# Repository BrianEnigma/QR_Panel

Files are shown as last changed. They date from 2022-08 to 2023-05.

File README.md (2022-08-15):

# QR Panel

Action Gif

## Overview

I recently ran across [a photo meme](https://www.reddit.com/r/DidntKnowIWantedThat/comments/kwxd3a/i_have_this_qr_code_sitting_behind_me_in_zoom/) which I guess has been kicking around for a couple of years, but was new to me. It shows off a QR code that, when scanned, turns in a table lamp sitting next to it. The person posting it mentioned it's in the background of video calls. I'm on a lot of video calls, and thought this would be an interesting project to re-make.

My QR panel is a self-contained unit that only needs power and WiFi. There are multicolor LEDs inside that shine through the QR code. When scanned, it takes you to a website that picks two random colors for you, and then sends those colors over an IoT MQTT queue to the panel. The panel then does a little 5-second spinny animation with those colors. With only 8 colors to choose from, the combinations aren't infinite, but are large enough (`8 choose 2 == 56`) for you to verify that you were the one that kicked off the animation.

This work is copyright 2022 by [Brian Enigma](https://github.com/BrianEnigma). It is licensed under a <a rel="license" href="http://creativecommons.org/licenses/by-nc-sa/3.0/">Creative Commons Attribution-NonCommercial-ShareAlike 3.0 Unported License</a>.

## Prior Work

This is based on some earlier work I did with the [Adafruit Feather Huzzah](https://www.adafruit.com/product/2821) and AWS IoT message queues. [You can find that work on my blog.](https://netninja.com/2022/08/11/using-the-adafruit-feather-huzzah-with-aws-iot/)

## Target Audience

This is presented mainly as a code repo of the physical pieces (laser cut and 3D printed), Feather firmware, and cloud software that went into this device. There is not a lot of hand-holding or instruction. The target audience has access to a laser cutter and 3D printer, knows how to solder, can program an Arduino-like device, and knows their way around the AWS control panel. While the blog post linked to in the “Prior Work” section, above, does a lot of hand-holding, this one does not.

## Bill of Material

- [Feather Huzzah](https://www.adafruit.com/product/2821)
- [NeoPixel string](https://www.adafruit.com/product/1138?length=1) (mine ended up being 52 LEDs)
- [Power Supply](https://www.adafruit.com/product/1466)
- [Power Connector](https://www.adafruit.com/product/368)
- [Microswitch](https://www.adafruit.com/product/1489)
- Four M3 screws for the corners: 30mm long, with nuts and nylon washers.
- Four M2 screws for the Feather: 10mm long, with nuts and nylon washers.
- [3D Parts](3D Parts/)
    - Four 3D printed corners (white)
- 1/8" Acrylic [Laser Parts](Laser Parts/)
    - One laser-cut back panel (black)
    - Four laser-cut edges (white)
    - One laser-cut front panel (translucent). I also added some cardstock behind it to better diffuse the light. It is important to fill in the etched QR code with black acrylic paint **BEFORE** peeling off the protective masking, since it doubles as a paint mask. You might need more than one coat. Once it's try, you can peel it off.
- Solder, wire, tape, glue, etc.

## QR Customization

You'll obviously need to change the QR Code etched in the front panel or you'll end up pointing to my panel's endpoint. I used the npm [qrcode](https://www.npmjs.com/package/qrcode) package.

## Hardware Frame

The hardware frame goes together easily. Four M3 screws go through the back panel, one at each corner. Each corner has a 3D printed piece. It has registration tabs that only align to the back panel in one way. The four edges clip into the corners, snapping into retaining tabs. The LED strip gets hot-glued around the outside (around the reset microswitch), facing inward. When everything's wired up and functioning, the front panel QR code affixes to the front.

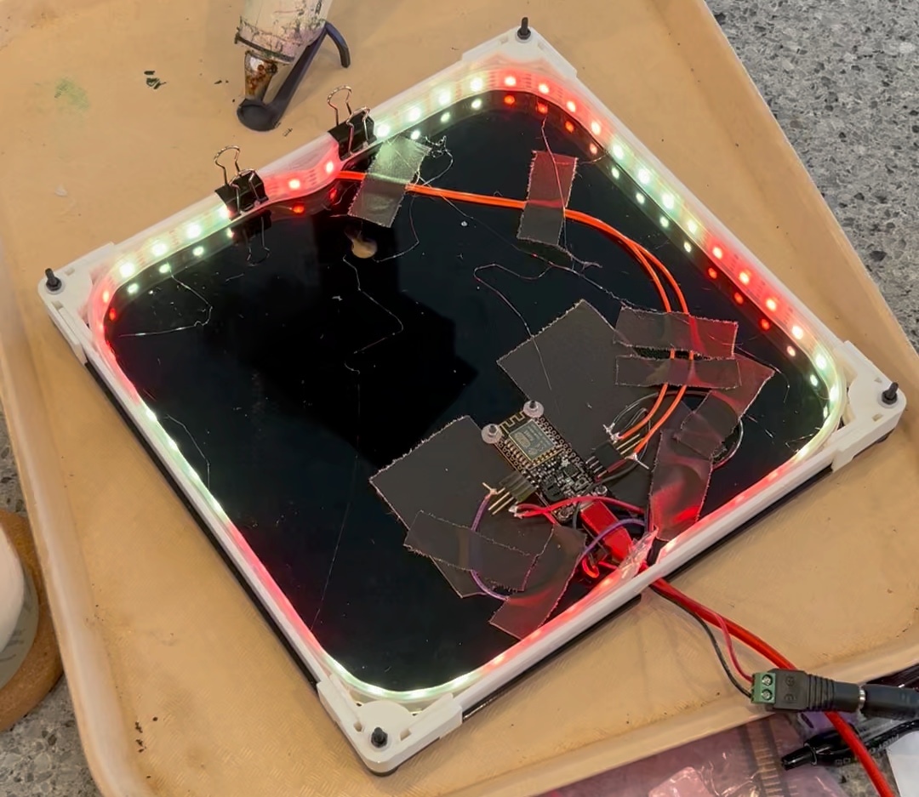
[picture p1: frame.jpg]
Frame

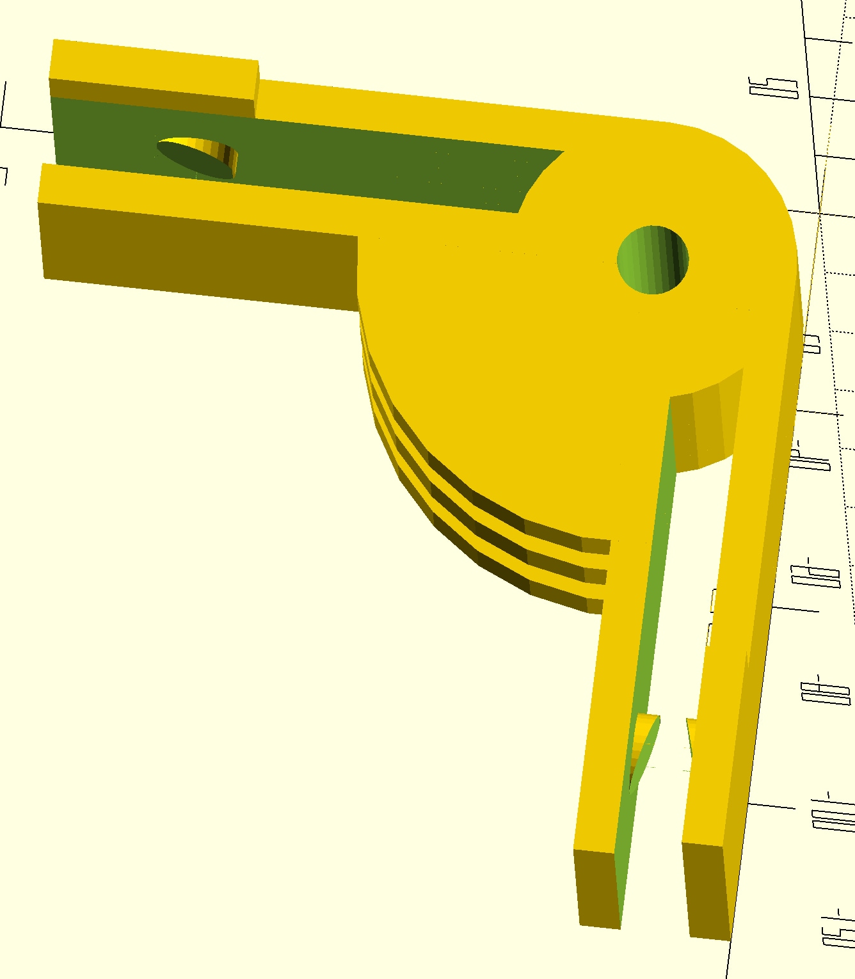
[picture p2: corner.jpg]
Corner

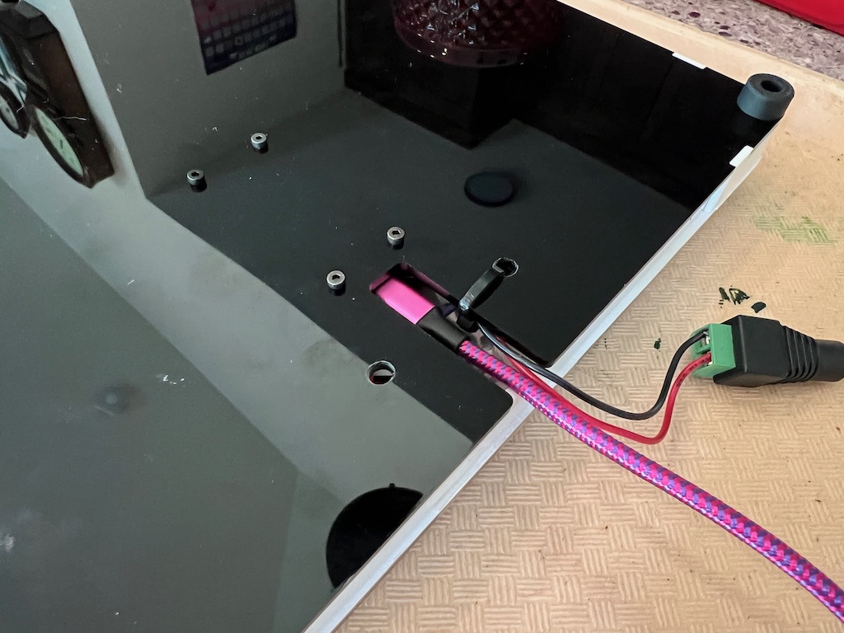
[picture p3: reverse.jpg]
Reverse


## Hardware Wiring

The hardware is fairly trivial:

- The microswitch goes to the little hole in the top. It connects between the Reset and Ground pins. It lets you “reboot” if there's a problem.
- Power gets wired from the power connector to the Battery and Ground pins.
- Power is also routed to the LED strip.
- Data is wired from pin 14 to the LED strip.

I had to tack down the microswitch with hot glue. I used a zip tie to help as a strain-relief for the power connector's leads.

## Initial Bringup

The code under [Arduino/led_bringup/](Arduino/led_bringup/) lets you test the LEDs.

The code on the above-mentioned blog post lets you test WiFi, AWS IoT, and MQTT.

The final code is under the [Arduino/QRPanel2/](Arduino/QRPanel2/) folder. You'll need to rename `secrets-example.h` and poke in your own specific wifi credentials, cert, and key.

## Cloud Infrastructure

I won't walk you through the details of the setup, but the control flow looks like this:

```
Cloudfront ⇒ S3 ⇒ API Gateway ⇒ Lambda ⇒ IoT MQTT ⇒ Adafruit Feather Huzzah (ESP8266)
```

- You'll need to create your MQTT and ensure it tests out correctly (according to that previous blog post).
- You'll need to create a Lambda and use the Python code found in the [Lambda/](Lambda/) folder.
    - Depending on your MQTT name, you'll need to change the variable up top.
    - Depending on where you're hosting the web piece, you will need to change the CORS code near the bottom.
- CHECKPOINT: At this point, you should be able to manually trigger your Python code in Lambda's interactive debug console and see the QR Panel update in realtime.
- Next, put an API Gateway in front of your Lamba. Take note of the URL.
- Put that URL into the `index.js` code in the [Web/live/](Web/live/) folder.
- Host your website somewhere. What I did was:
    - Create an S3 bucket for static hosting.
    - Create a subdomain under my main domain name.
    - Create a certificate for that subdomain in the AWS Certificate Manager.
    - Create a CloudFront distribution in front of the S3 bucket that uses that certificate.

## Operation

- When powering up, the outline of the QR code progressively lights up green. It's a progress bar indicating: wifi connectivity, IoT connectivity, NTP server connectivity, and first heartbeat.
- Once fully green, the device is connected ready to go. The QR Panel changes to white. This is the default state.
- When an MQTT message is received with a color pair, you get a spin animation.
    - If the message cannot be parsed, you get a brief red frame.
    - Occasionally, the animation takes a bit too long, the Huzzah disconnects from AWS, and it has to go through the green progress bar again.
- In the event of any other kind of error (beyond just parsing the MQTT payload), the QR Panel pulses red. There's no return from this beyond hitting the reset button on the top. This includes problems connecting to wifi, problems connecting to AWS, and similar.

## TODO

- I've caught the common error states in the firmware code, but there are a few spots that use infinite loops instead of timeouts.
- The firmware is single-threaded and the animation does not ever yield to the MQTT client. Depending on heartbeat timing, this can cause a disconnect/reconnect. This reconnect is handled in the code, but it would be more elegant to allow the MQTT to be serviced or kept alive. (But this, in turn, adds callback function re-entrance into the mix, greatly increasing the code complexity on a little memory-constrained device. Addressing this felt just a bit too much for a 1.0 release.)

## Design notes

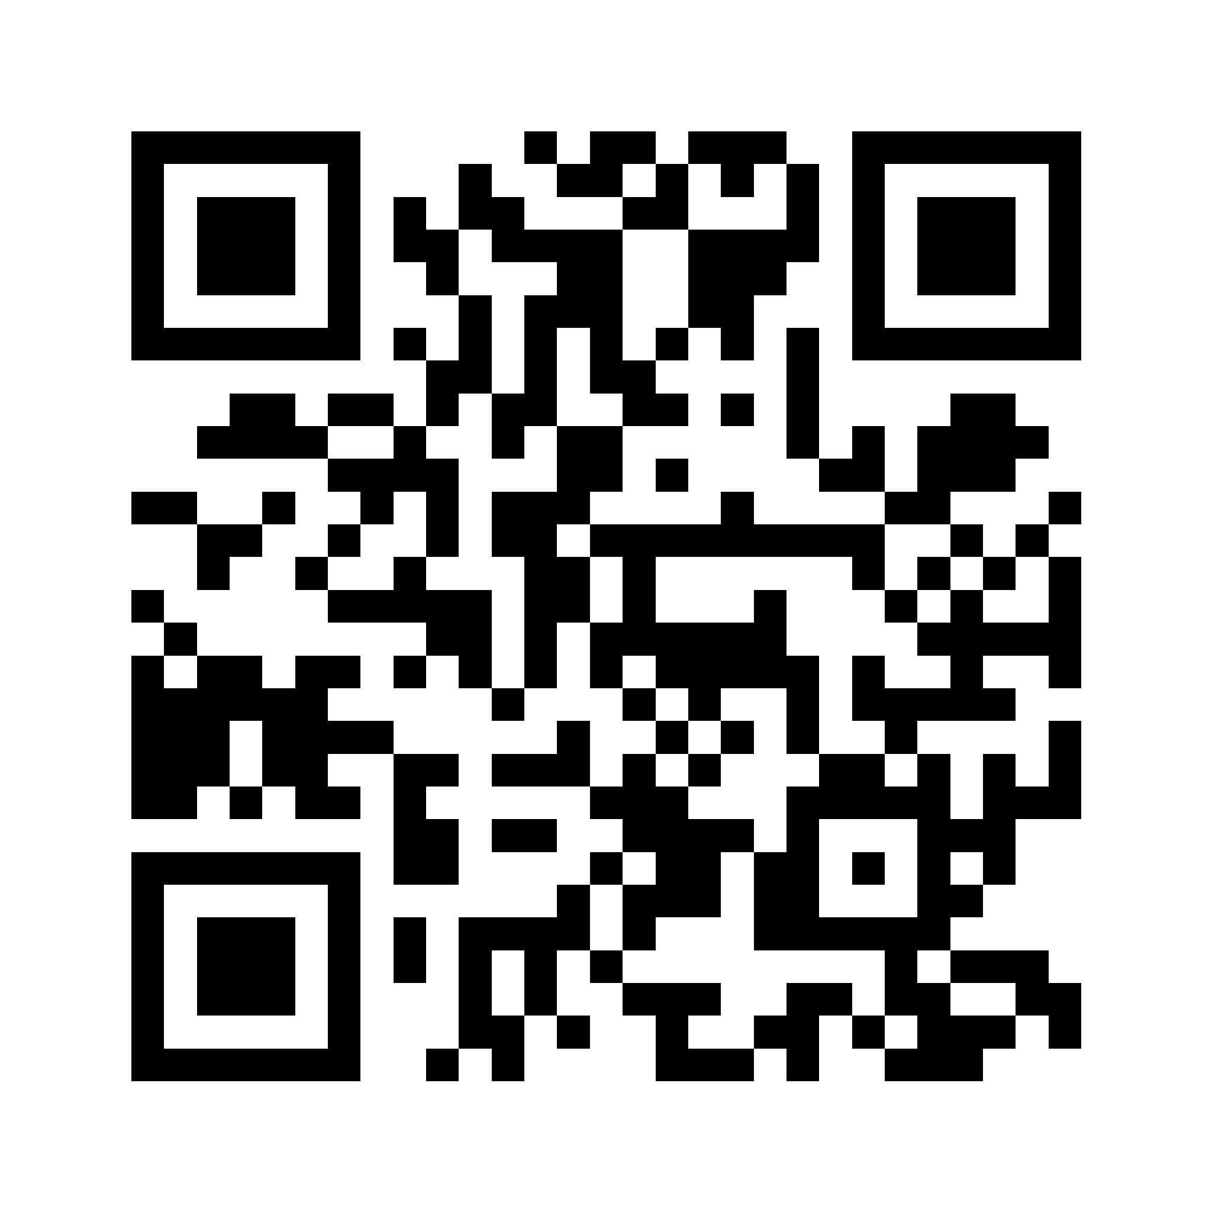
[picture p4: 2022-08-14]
QR/qr.png

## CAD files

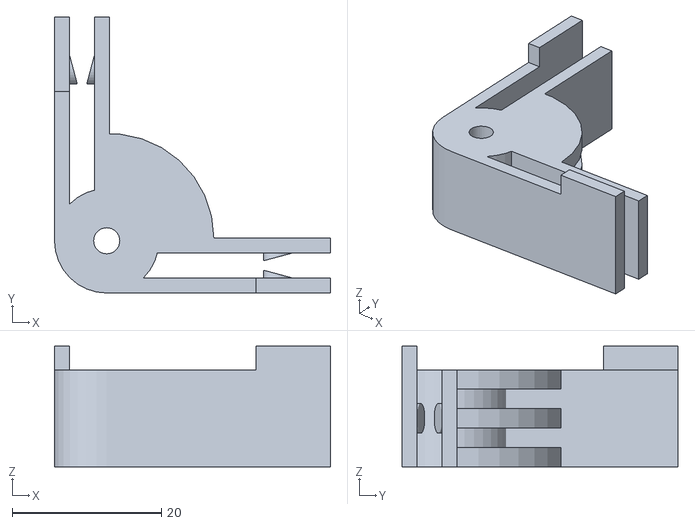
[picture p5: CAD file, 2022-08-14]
3D Parts/corner.stl
37.0 x 37.0 x 16.2

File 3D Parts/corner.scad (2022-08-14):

CORNER_THICKNESS = 13.0;
SCREW_DIAMETER = 3.5;
SCREW_WALL_THICKNESS = (14 - SCREW_DIAMETER) / 2;
DETAIL = 32;
TAB_THICKNESS = 3.175;
TAB_TOLERANCE = 0.1;
TAB_WALL_THICKNESS = 2;
TAB_LENGTH = 30.0;
SNAP_DIAMETER = 4;
SNAP_HEIGHT = TAB_THICKNESS / 3;
SNAP_OFFSET_FROM_CORNER = 30;
REGISTRATION_TAB_LENGTH = 10;
REGISTRATION_TAB_DEPTH = 3.175;

// Calculated Values
OUTER_CYLINDER = SCREW_DIAMETER / 2 + SCREW_WALL_THICKNESS;
INNER_BOX_THICKNESS = TAB_THICKNESS + TAB_TOLERANCE * 2;
OUTER_BOX_THICKNESS = INNER_BOX_THICKNESS + TAB_WALL_THICKNESS * 2;
OUTER_BOX_WALL_THICKNESS = (OUTER_BOX_THICKNESS - INNER_BOX_THICKNESS) / 2;

module screwhole()
{
	translate(v = [OUTER_CYLINDER, OUTER_CYLINDER, 0])
		difference()
		{
			cylinder(r = OUTER_CYLINDER, h = CORNER_THICKNESS, $fn = DETAIL);
			translate(v = [0, 0, -1])
				cylinder(r = SCREW_DIAMETER / 2, h = CORNER_THICKNESS + 2, $fn = DETAIL);
		}
}

module tab()
{
	union()
	{
		translate(v = [0, SCREW_DIAMETER / 2 + SCREW_WALL_THICKNESS, 0])
			difference()
			{
				cube(size = [OUTER_BOX_THICKNESS, TAB_LENGTH, CORNER_THICKNESS]);
				translate(v = [TAB_WALL_THICKNESS, (OUTER_BOX_THICKNESS - INNER_BOX_THICKNESS) / 2, -1])
					cube(size = [INNER_BOX_THICKNESS, TAB_LENGTH, CORNER_THICKNESS + 2]);

			}
		snap1();
		snap2();
	}
}

module snap1()
{
	translate(v = [OUTER_BOX_WALL_THICKNESS - 0.01, SNAP_OFFSET_FROM_CORNER, CORNER_THICKNESS / 2])
		difference()
		{
			rotate(a = [0, 90, 0])
				cylinder(r = SNAP_DIAMETER / 2, h = SNAP_HEIGHT, $fn = DETAIL);
			translate(v = [0, SNAP_DIAMETER / 2, 0])
				rotate(a = [0, 0, 15])
					translate(v = [0, SNAP_DIAMETER * -1, SNAP_DIAMETER / -2])
						cube(size = [SNAP_DIAMETER, SNAP_DIAMETER, SNAP_DIAMETER]);
		}
}

module snap2()
{
	translate(v = [OUTER_BOX_WALL_THICKNESS + INNER_BOX_THICKNESS + 0.01, SNAP_OFFSET_FROM_CORNER, CORNER_THICKNESS / 2])
		scale(v = [-1, 1, 1])
			difference()
			{
				rotate(a = [0, 90, 0])
					cylinder(r = SNAP_DIAMETER / 2, h = SNAP_HEIGHT, $fn = DETAIL);
				translate(v = [0, SNAP_DIAMETER / 2, 0])
					rotate(a = [0, 0, 15])
						translate(v = [0, SNAP_DIAMETER * -1, SNAP_DIAMETER / -2])
							cube(size = [SNAP_DIAMETER, SNAP_DIAMETER, SNAP_DIAMETER]);
			}
}


module tabs()
{
	difference()
	{
		union()
		{
			tab();
			translate(v = [0, OUTER_BOX_THICKNESS, 0])
			rotate(a = [0, 0, -90])
				tab();
		}
		translate(v = [OUTER_CYLINDER, OUTER_CYLINDER, -1])
			cylinder(r = SCREW_DIAMETER / 2, h = CORNER_THICKNESS + 2, $fn = DETAIL);
	}
}

module strain_reliefs()
{
	difference()
	{
		for (z_pos = [0 : 2])
		{
			translate(v = [OUTER_BOX_THICKNESS - 0.01, OUTER_BOX_THICKNESS - 0.01, CORNER_THICKNESS / 5 * z_pos * 2])
				intersection()
				{
					cylinder(r = OUTER_CYLINDER * 2, h = CORNER_THICKNESS / 5);
					cube(size = [OUTER_CYLINDER * 2, OUTER_CYLINDER * 2, CORNER_THICKNESS]);
				}
		}
		translate(v = [OUTER_CYLINDER, OUTER_CYLINDER, -1])
			cylinder(r = SCREW_DIAMETER / 2, h = CORNER_THICKNESS + 2, $fn = DETAIL);
	}
}

module registration_tabs()
{
	union()
	{
		translate(v = [0, TAB_LENGTH + SCREW_DIAMETER / 2 + SCREW_WALL_THICKNESS - REGISTRATION_TAB_LENGTH, CORNER_THICKNESS - 0.01])
			cube(size = [OUTER_BOX_WALL_THICKNESS, REGISTRATION_TAB_LENGTH, REGISTRATION_TAB_DEPTH]);
		translate(v = [TAB_LENGTH + SCREW_DIAMETER / 2 + SCREW_WALL_THICKNESS - REGISTRATION_TAB_LENGTH, 0, CORNER_THICKNESS - 0.01])
			cube(size = [REGISTRATION_TAB_LENGTH, OUTER_BOX_WALL_THICKNESS, REGISTRATION_TAB_DEPTH]);
	}
}

union()
{
	screwhole();
	tabs();
	strain_reliefs();
	registration_tabs();
	//snap1();
	//snap2();
}

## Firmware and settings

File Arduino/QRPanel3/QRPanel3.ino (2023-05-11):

#include "secrets.h"
#include <WiFiClientSecure.h>
#include <MQTTClient.h>
#include <ArduinoJson.h>
#include <ESP8266WiFi.h>
#include <NTPClient.h>
#include <WiFiUdp.h>

#include <Adafruit_NeoPixel.h>
#ifdef __AVR__
    #include <avr/power.h> // Required for 16 MHz Adafruit Trinket
#endif
#define LED_PIN    14
#define LED_COUNT 52
Adafruit_NeoPixel strip(LED_COUNT, LED_PIN, NEO_GRB + NEO_KHZ800);

WiFiClientSecure iot = WiFiClientSecure();
MQTTClient client = MQTTClient(256);

WiFiUDP ntpUDP;
NTPClient timeClient(ntpUDP, "north-america.pool.ntp.org"); // prep NTP server connectivity
X509List clientCertificate(AWS_CRT);
PrivateKey clientPrivateKey(AWS_PRIVATE);
X509List caCertificate(AWS_CA);

uint32_t alertColor1;
uint32_t alertColor2;
bool shouldAlert = false;

/// Display a progress indicator up both sides of the QR code.
/// @param step The current step number.
/// @param steps The total number of steps.
void displayProgress(unsigned char step, unsigned char steps)
{
    static int s_previousProgressCount = 0;
    unsigned int ledProgressCount = LED_COUNT / 2;
    float percent = (float) step / (float) steps;
    ledProgressCount = (int)((float) ledProgressCount * percent);
    Serial.print("Progress: ");
    Serial.print(step);
    Serial.print(" of ");
    Serial.print(steps);
    Serial.print(" -- ");
    Serial.println(percent);
    if (s_previousProgressCount > ledProgressCount)
        s_previousProgressCount = 0;
    // Instantly fill in previous count.  In theory, it should already be filled in.
    strip.clear();
    for (int i = 0; i < s_previousProgressCount; i++)
    {
        strip.setPixelColor(i, strip.Color(0x00, 0xff, 0x00));
        strip.setPixelColor(LED_COUNT - i - 1, strip.Color(0x00, 0xff, 0x00));
    }
    strip.show();
    // Fill in from previous to current, only a little slow like an animation.
    for (int i = s_previousProgressCount; i < ledProgressCount; i++)
    {
        delay(40);
        strip.setPixelColor(i, strip.Color(0x00, 0xff, 0x00));
        strip.setPixelColor(LED_COUNT - i - 1, strip.Color(0x00, 0xff, 0x00));
        strip.show();
    }
    s_previousProgressCount = ledProgressCount;
}

/// Display a fade-in/fade-out red ring around the QR code.
/// @param limitedError If true, only blink the error a few times, then return. If false, 
/// then this function does not return. You will need to manually reset the
/// device.
void displayError(bool limitedError)
{
#define RED_MIN 0x20
#define RED_MAX 0xD0
#define RED_STEP 0x04
    int redDirection = 1;
    int redValue = RED_MIN;
    int blinkCount = 0;
    Serial.println("***** ERROR *****");
    while (true)
    {
        for (int pos = 0; pos < LED_COUNT; pos++)
            strip.setPixelColor(pos, strip.Color(redValue, 0x00, 0x00));
        strip.show();
        delay(50);
        redValue += redDirection * RED_STEP;
        if (redValue <= RED_MIN)
        {
            redDirection = 1;
            redValue = RED_MIN;
            if (limitedError)
            {
                if (++blinkCount >= 3)
                    return;
            }
        }
        if (redValue >= RED_MAX)
        {
            redDirection = -1;
            redValue = RED_MAX;
        }
    }
}

void displayWhite()
{
    for (int pos = 0; pos < LED_COUNT; pos++)
        strip.setPixelColor(pos, strip.Color(0xff, 0xff, 0xff));
    strip.show();
}

/// Attempt to connect to wifi using the information in secrets.h.
/// @return true on success, false on fail.
bool connectToWiFi() // connect to local wifi network
{
    Serial.println("\nConnecting to Wi-Fi");
    
    //WiFi.mode(WIFI_STA);
    WiFi.begin((char *)WIFI_SSID, (char *)WIFI_PASSWORD);
    while (WiFi.status() != WL_CONNECTED) 
    {
        delay(200);
        Serial.print("..");
        // TODO: TIMEOUT CONDITION
    }

    Serial.println("\nSUCCESS: Connected to Wi-Fi");
    Serial.print("Wi-Fi SSID:  ");
    Serial.println(WIFI_SSID);
    return true;
}

/// Callback to indicate a MQTT message has been received.
void messageReceived(String &topic, String &payload) 
{
    unsigned char r, g, b;
    Serial.println("incoming: " + topic + " - " + payload);
    digitalWrite(LED_BUILTIN, LOW);
    StaticJsonDocument<256> doc;
    DeserializationError error = deserializeJson(doc, payload);
    if (error)
    {
        displayError(true);
        for (int pos = 0; pos < LED_COUNT; pos++)
            strip.setPixelColor(pos, strip.Color(0xff, 0xff, 0xff));
        strip.show();
        return;
    }
    /*
Example doc. This library doesn't seem to want to do nested arrays.
{
    "color0":[255,0,0],
    "color1":[255,0,0]
}
echo '{"color0":[255,0,255],"color1":[0,255,255]}' | base64
aws --profile home iot-data publish --topic qr_trigger --payload eyJjb2xvcjAiOlsyNTUsMCwwXSwiY29sb3IxIjpbMCwwLDI1NV19Cg==
aws --profile home iot-data publish --topic qr_trigger --payload eyJjb2xvcjAiOlsyNTUsMCwwXSwiY29sb3IxIjpbMjU1LDI1NSwwXX0K
aws --profile home iot-data publish --topic qr_trigger --payload eyJjb2xvcjAiOlsyNTUsMCwyNTVdLCJjb2xvcjEiOlswLDI1NSwyNTVdfQo=
     */
    r = doc["color0"][0];
    g = doc["color0"][1];
    b = doc["color0"][2];
    Serial.print(r); Serial.print(","); Serial.print(g); Serial.print(","); Serial.println(b);
    alertColor1 = Adafruit_NeoPixel::Color(r, g, b);
    r = doc["color1"][0];
    g = doc["color1"][1];
    b = doc["color1"][2];
    Serial.print(r); Serial.print(","); Serial.print(g); Serial.print(","); Serial.println(b);
    alertColor2 = Adafruit_NeoPixel::Color(r, g, b);
    shouldAlert = true;
    digitalWrite(LED_BUILTIN, HIGH);
    // Note: Do not use the client in the callback to publish, subscribe or
    // unsubscribe as it may cause deadlocks when other things arrive while
    // sending and receiving acknowledgments. Instead, change a global variable,
    // or push to a queue and handle it in the loop after calling `client.loop()`.
}

/// Make a connection to the AWS IOT service. Set up callbacks.
/// @return true on success, false on fail.
bool connectToAWSIoT()
{
    Serial.print("\n\nConnecting to AWS IoT");
    
    iot.setClientRSACert(&clientCertificate, &clientPrivateKey);
    iot.setTrustAnchors(&caCertificate);
    iot.setInsecure(); // Blindly trust the server certs.
    client.begin(AWS_ENDPOINT, 8883, iot);
    
    while (!client.connect(AWS_THINGNAME)) 
    {
        Serial.print(".");
        delay(200);
        // TODO: CATCH TIMEOUT
    }
    
    if (!client.connected()) 
    {
        Serial.println("\nERROR: AWS IoT Connection Timeout");
        return false;
    }
    
    client.subscribe(MQTT_SUB_TOPIC); // subscribe to MQTT topic
    client.onMessage(messageReceived);
    
    // display AWS IoT resource names in console
    Serial.println("\nSUCCESS: AWS IoT Endpoint Connected\n");
    Serial.print("\nAWS IoT Publish Topic:  ");
    Serial.println(MQTTT_PUB_TOPIC);
    Serial.print("\nAWS IoT Subscribe Topic:  ");
    Serial.println(MQTT_SUB_TOPIC);
    Serial.print("\nAWS IoT Thing Name:  ");
    Serial.println(AWS_THINGNAME);
    Serial.print("\nAWS IoT Endpoint:  ");
    Serial.println(AWS_ENDPOINT);
    Serial.println("\n");
    return true;
}

/// Publish a heartbeat payload to MQTT.
/// @return true on success, false on fail.
bool publishHeartbeat()
{
    StaticJsonDocument<200> doc;
    doc["time"] = timeClient.getEpochTime(); // get current NPT time/date in epoch format
    doc["heartbeat"] = 1;
    char jsonBuffer[512];
    
    serializeJson(doc, jsonBuffer);
    Serial.println(jsonBuffer);
    client.publish(MQTTT_PUB_TOPIC, jsonBuffer); // publish to MQTT topic
    // TODO: ERROR CONDITION
    return true;
}

/// Publish a heartbeat payload to MQTT, but only if 30 seconds has elapsed since the last heartbeat.
/// @return true on success, false on fail.
bool maybePublishHeartbeat()
{
    static unsigned char delayCounter = 0;
    // This is called roughly every second. We'll send a heartbeat roughly every 10 seconds.
    if (delayCounter++ >= 30)
    {
        delayCounter = 0;
        return publishHeartbeat();
    }
    return true;
}

/// Set up the hardware and libraries.
void setup() 
{
    Serial.begin(115200);
    pinMode(LED_BUILTIN, OUTPUT);
    digitalWrite(LED_BUILTIN, LOW); // Starting initialization.
    strip.begin();
    strip.clear();
    strip.show();
    strip.setBrightness(255);

    delay(2000); // some delay

    displayProgress(1, 4);
    if (!connectToWiFi())
        displayError(false);
    Serial.println("Starting NTP time client.");
    timeClient.begin();
    timeClient.forceUpdate();
    while (!timeClient.isTimeSet())
    {
        Serial.print(".");
        delay(1000);
    }
    Serial.println(timeClient.getFormattedTime());
    displayProgress(2, 4);
    if (!connectToAWSIoT())
        displayError(false);
    displayProgress(3, 4);
    if (!publishHeartbeat())
        displayError(false);
    delay(100);
    displayProgress(4, 4);
    delay(100);
    timeClient.begin();
    displayWhite();
    digitalWrite(LED_BUILTIN, HIGH); // Finished initialization.
}

void doAlertAnimation()
{
    const unsigned char COLOR_TABLE[] = {0, 0, 0, 0, 1, 1, 1, 1};
    const int COLOR_TABLE_SIZE = sizeof(COLOR_TABLE) / sizeof(COLOR_TABLE[0]);
    static unsigned char offset = 0;
    // Animate startup...
    strip.clear();
    strip.show();
    for (unsigned int pos = 0; pos < LED_COUNT; pos++)
    {
        unsigned char color = COLOR_TABLE[(pos + offset) % COLOR_TABLE_SIZE];
        if (color == 0)
        {
            strip.setPixelColor(pos, alertColor1);
        } else {
            strip.setPixelColor(pos, alertColor2);
        }
        strip.show();
        delay(20);
    }
    // Animate...
    for (int counter = 0; counter < 50; counter++)
    {
        for (unsigned int pos = 0; pos < LED_COUNT; pos++)
        {
            unsigned char color = COLOR_TABLE[(pos + offset) % COLOR_TABLE_SIZE];
            if (color == 0)
            {
                strip.setPixelColor(pos, alertColor1);
            } else {
                strip.setPixelColor(pos, alertColor2);
            }
        }
        strip.show();
        offset += COLOR_TABLE_SIZE - 1;
        offset = offset % COLOR_TABLE_SIZE;
        delay(80);
    }
    // Animate clear...
    for (unsigned int pos = 0; pos < LED_COUNT; pos++)
    {
        strip.setPixelColor(pos, strip.Color(0xff, 0xff, 0xff));
        strip.show();
        delay(10);
    }
}

unsigned char errorCount = 0;
/// Main control loop.
void loop() 
{
    bool error = false;
    // Update doesn't return a reliable error, only that the update did or did not happen.
    // So we're ignoring the return value and assuming a bad update will have side-effects
    // elsewhere that we'll catch (e.g. AWS IoT cert errors).
    timeClient.update();
    if (!maybePublishHeartbeat())
    {
        Serial.println("Error sending heartbeat.");
        error = true;
    }
    if (!client.loop())
    {
        Serial.println("Error in MQTT loop.");
        Serial.println(client.lastError());
        Serial.println(client.returnCode());
        error = true;
    }
    if (shouldAlert)
    {
        doAlertAnimation();
        shouldAlert = false;
    }
    if (!client.connected())
    {
        Serial.println("Got disconnected! Reconnecting.");
        displayProgress(2, 4);
        if (!connectToAWSIoT())
            error = true;
        else
            displayWhite();
    }
    if (error)
    {
        errorCount++;
        if (errorCount >= 10)
        {
            Serial.println("Too many errors. Aborting.");
            displayError(false);
        }
    } else {
        errorCount = 0;
    }
    delay(1000);
}

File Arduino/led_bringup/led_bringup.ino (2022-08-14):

// A basic everyday NeoPixel strip test program.

// NEOPIXEL BEST PRACTICES for most reliable operation:
// - Add 1000 uF CAPACITOR between NeoPixel strip's + and - connections.
// - MINIMIZE WIRING LENGTH between microcontroller board and first pixel.
// - NeoPixel strip's DATA-IN should pass through a 300-500 OHM RESISTOR.
// - AVOID connecting NeoPixels on a LIVE CIRCUIT. If you must, ALWAYS
//   connect GROUND (-) first, then +, then data.
// - When using a 3.3V microcontroller with a 5V-powered NeoPixel strip,
//   a LOGIC-LEVEL CONVERTER on the data line is STRONGLY RECOMMENDED.
// (Skipping these may work OK on your workbench but can fail in the field)

#include <Adafruit_NeoPixel.h>
#ifdef __AVR__
 #include <avr/power.h> // Required for 16 MHz Adafruit Trinket
#endif

// Which pin on the Arduino is connected to the NeoPixels?
// On a Trinket or Gemma we suggest changing this to 1:
#define LED_PIN    14

// How many NeoPixels are attached to the Arduino?
#define LED_COUNT 52

// Declare our NeoPixel strip object:
Adafruit_NeoPixel strip(LED_COUNT, LED_PIN, NEO_GRB + NEO_KHZ800);
// Argument 1 = Number of pixels in NeoPixel strip
// Argument 2 = Arduino pin number (most are valid)
// Argument 3 = Pixel type flags, add together as needed:
//   NEO_KHZ800  800 KHz bitstream (most NeoPixel products w/WS2812 LEDs)
//   NEO_KHZ400  400 KHz (classic 'v1' (not v2) FLORA pixels, WS2811 drivers)
//   NEO_GRB     Pixels are wired for GRB bitstream (most NeoPixel products)
//   NEO_RGB     Pixels are wired for RGB bitstream (v1 FLORA pixels, not v2)
//   NEO_RGBW    Pixels are wired for RGBW bitstream (NeoPixel RGBW products)


// setup() function -- runs once at startup --------------------------------

void setup() {
  // These lines are specifically to support the Adafruit Trinket 5V 16 MHz.
  // Any other board, you can remove this part (but no harm leaving it):
#if defined(__AVR_ATtiny85__) && (F_CPU == 16000000)
  clock_prescale_set(clock_div_1);
#endif
  // END of Trinket-specific code.

  strip.begin();           // INITIALIZE NeoPixel strip object (REQUIRED)
  strip.show();            // Turn OFF all pixels ASAP
  strip.setBrightness(255); // Set BRIGHTNESS to about 1/5 (max = 255)
}

void update() {
    const unsigned char COLOR_TABLE[] = {0, 0, 0, 0, 1, 1, 1, 1};
    const int COLOR_TABLE_SIZE = sizeof(COLOR_TABLE) / sizeof(COLOR_TABLE[0]);
    static unsigned char offset = 0;
    for (unsigned int pos = 0; pos < LED_COUNT; pos++)
    {
        unsigned char color = COLOR_TABLE[(pos + offset) % COLOR_TABLE_SIZE];
        if (color == 0)
        {
            strip.setPixelColor(pos, strip.Color(0xff, 0x00, 0x00));    
        } else {
            strip.setPixelColor(pos, strip.Color(0xff, 0xff, 0x00));    
        }
    }
    strip.show();
    offset += COLOR_TABLE_SIZE - 1;
    offset = offset % COLOR_TABLE_SIZE;
}

void loop() {
    update();
    delay(100);
}

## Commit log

2022-08-14 First post!
    [corner.scad, corner.stl]
2022-08-21 Animate the progress bar, tighten up animation timing.
    - Progress bar fills in more like a progress bar now.
    - Tightening up the speed of the animation will hopefully cause fewer
    IoT MQTT drops, which means seeing the progress bar between scans is
    less likely to happen.
    [QRPanel3.ino]
